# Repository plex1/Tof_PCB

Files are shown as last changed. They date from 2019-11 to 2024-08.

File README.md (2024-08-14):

# Time-of-Flight (ToF) PCB 

Contains optical transceiver for lidar or optical communication applications.

Laser diode options:
-  OPV310
-  SPL90 (not extensively tested)
   - Mods required: The A version of the NCP81074A of the MOSFET driver should be used. The supply voltage for the Mosfet driver should be increased from 5V to 12V. The peak power can be considerably increased with a higher voltage and lower shunt resistor value. In this case the duty cycle should be increased correspondingly for eye safety.

Photo diodes options:
- MTAPD-06-013
- SiPM MICRORB-10020-MLP-TR1

## Libraries

Uses the following libraries:
- KiCad Symbol Library: [ioda_symbols](https://github.com/plex1/ioda_symbols)
- KiCad Footprint Library: [ioda_footprints](https://github.com/plex1/ioda_footprints)

## Image
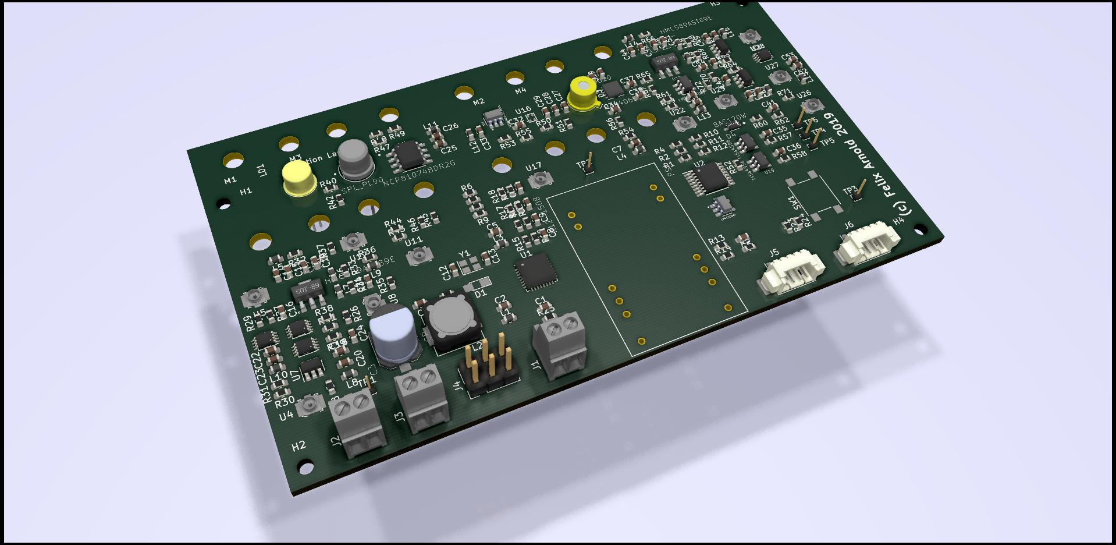
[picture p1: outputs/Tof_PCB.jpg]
Render


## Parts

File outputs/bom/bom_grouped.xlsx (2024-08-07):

Ref | Qnty | Value | Footprint | Digi-Key_PN | Part PCBWay will supply | Comment
C1, C2, C5, C6, C7, C15, C18, C19, C23, C26, C30, C40, C43, C45, C46, C47, C51, C53, C56, C58, C59, C60, C61, C62, C63, C64, C67, C69, C72, | 29 | 100nF | Capacitor_SMD:C_0603_1608Metric | 490-3285-1-ND | GRM188R72A104KA35D
C3, | 1 | 100uF | IODA_Lib:CAPAE660X800N | PCE5024CT-ND | EEE-FTH101XAP
C4, C8, C9, C10, C11, C14, C16, C17, C20, C21, C22, C25, C31, C32, C33, C34, C35, C36, C37, C38, C39, C41, C42, C44, C48, C49, C50, C52, C54, C55, C57, C65, C66, C68, C70, C71, C73, C74, C75, C76, C79, C80, C81, | 43 | 2.2uF | Capacitor_SMD:C_0603_1608Metric | 490-12740-1-ND | GRM188R61H225ME11D
C12, C13, | 2 | 16pF | Capacitor_SMD:C_0603_1608Metric | 399-7863-1-ND | C0603C160J5GACTU
C27, C28, C29, C78, | 4 | 10nF, 250V | Capacitor_SMD:C_0603_1608Metric | 732-12168-1-ND | 885342206006
D1, D6, | 2 | LED | LEDs:LED_0805 | 160-1423-1-ND | LTST-C171GKT
D4, | 1 | BAS170W | IODA_Lib:SOD2513X114N | BAS170WS-E3-08GICT-ND | BAS170WS-E3-08
D5, | 1 | SMBJ6.0A | OLIMEX_Diodes-FP:DO214AA_1(K)-2(A) | SMBJ6.0ABCT-ND | SMBJ6.0A
J1, J2, J3, J7, | 4 | Screw_Terminal_01x02 | IODA_Lib:ScrewTerminal_1x02_P2.54mm_Vertical | A98333-ND | 282834-2
J4, | 1 | Conn_02x03_Odd_Even | Connector_PinHeader_2.54mm:PinHeader_2x03_P2.54mm_Vertical | 609-3210-ND | 67996-206HLF | Part we will supply is substitute made in China.
J5, J6, | 2 | Conn_01x04 | Connector_Molex:Molex_PicoBlade_53261-0471_1x04-1MP_P1.25mm_Horizontal | WM7622CT-ND | 0532610471
L1, L3, L4, L5, L8, L10, L11, L12, L13, L14, L15, L16, L17, L20, L22, | 15 | bead | Inductor_SMD:L_0603_1608Metric | 490-5216-1-ND | BLM18HE152SN1D
L2, | 1 | 6.8uH | IODA_Lib:INDP7373X46N | 811-1180-1-ND | 46682C
L6, L7, L9, L18, L19, L21, | 6 | 10uH | Inductor_SMD:L_0603_1608Metric | 490-4025-1-ND | LQM18FN100M00D
R1, R6, R7, R8, R9, R23, R24, R27, R37, R39, | 10 | 0R | Resistor_SMD:R_0603_1608Metric | RMCF0603ZT0R00CT-ND | RMCF0603ZT0R00
R2, R3, R4, R13, R30, R31, R84, | 7 | 2.2k | Resistor_SMD:R_0603_1608Metric | RMCF0603FT2K20CT-ND | RMCF0603FT2K20
R5, R15, R18, R19, R20, R21, R22, R25, R33, R34, R54, R56, R57, R58, R60, R68, R69, R71, R80, R92, R93, | 21 | 10k | Resistor_SMD:R_0603_1608Metric | P10.0KHCT-ND | ERJ-3EKF1002V
R14, R29, R35, R42, R43, R55, R61, R72, R73, R78, R79, R86, | 12 | 200R | Resistor_SMD:R_0603_1608Metric | RHM200ADCT-ND | ESR03EZPF2000
R16, R40, R44, | 3 | 100R | Resistor_SMD:R_0603_1608Metric | RMCF0603FT100R | RMCF0603FT100R
R17, R51, R74, | 3 | 1M | Resistor_SMD:R_0603_1608Metric | 311-1.00MHRCT-ND | RC0603FR-071ML
R28, R45, R52, R53, R70, R85, | 6 | 50R | Resistor_SMD:R_0603_1608Metric | 541-56.0SCT-ND | CRCW060356R0FKEAHP
R32, R66, | 2 | 1.8R | Resistor_SMD:R_0603_1608Metric | 541-1.80CCCT-ND | CRCW08051R80FKEA
R47, | 1 | 4.7R | Resistor_SMD:R_0603_1608Metric | RNCP0603FTD4R70CT-ND | RNCP0603FTD4R70
R59, | 1 | 75R | Resistor_SMD:R_0603_1608Metric | RNCP0603FTD75R0CT-ND | RNCP0603FTD75R0
R62, R75, R76, R77, | 4 | 100k | Resistor_SMD:R_0603_1608Metric | RMCF0603FT110K | RMCF0603FT110K
R64, R89, R90, R91, | 4 | 22R | Resistor_SMD:R_0603_1608Metric | A129668CT-ND | CRGCQ0603F22R
TP1, TP2, TP3, TP4, TP5, TP6, TP7, TP8, TP9, TP10, | 10 | TestPoint | Connector_PinHeader_1.00mm:PinHeader_1x01_P1.00mm_Vertical | 732-5314-ND | 61300111121 | Part we will supply is substitute made in China.
U1, | 1 | ATmega328PB-MU | Package_DFN_QFN:QFN-32-1EP_5x5mm_P0.5mm_EP3.1x3.1mm | ATMEGA328PB-MURCT-ND | ATMEGA328PB-MUR
U4, U5, U8, U11, U12, U17, U22, U27, U28, U29, U32, U33, U35, | 13 | UMCC_50Ohm | IODA_Lib:Molex_734120114_UMC_RF_CONN_Vertical | A118077CT-ND | 1909763-1
U6, U25, | 2 | HMC589AST89E | IODA_Lib:SOT150P410X160-3N | 1127-3329-1-ND | HMC589AST89ETR
U7, U23, U24, | 3 | TLV3501 | IODA_Lib:SOT-23-6 | 296-43611-1-ND | TLV3501AIDR
U9, U10, U13, U26, U30, | 5 | NC7WZ00K8X | IODA_Lib:VSSOP-8_2.4x2.1mm_P0.5mm | NC7WZ00K8XCT-ND | NC7WZ00K8X
U14, | 1 | NCP81074BDR2G | IODA_Lib:SOIC-8-127P600X175-8N | NCP81074BDR2GOSCT-ND | NCP81074BDR2G
U15, | 1 | LMH6559MF | IODA_Lib:SOT95PX285X122-5N | 296-46123-1-ND | LMH6559MF
U18, U19, | 2 | ts5a4596 | IODA_Lib:SOT95PX285X122-5N | 296-17709-1-ND | TS5A4596DBVR
U20, | 1 | MAX40659 | IODA_Lib:SON65P300X300X80-9N | MAX40659ETA+TCT-ND | MAX40659ETA+T
U21, | 1 | LP5907MFX-3.3_NOPB | IODA_Lib:SOT95P280X145-5N | 296-38557-1-ND | LP5907MFX-3.3/NOPB
U31, | 1 | LM321 | Package_TO_SOT_SMD:SOT-23-5 | LM321MFX/NOPBCT-ND | LM321MFX/NOPB
U34, | 1 | NC7WZ16 | IODA_Lib:SOT65P210X110-6N | NC7WZ16P6XCT-ND | NC7WZ16P6X
Y1, | 1 | Crystal_GND24 | Crystal:Crystal_SMD_2520-4Pin_2.5x2.0mm | SER4068CT-ND | FA-20H 16.0000MF10Z-AJ0

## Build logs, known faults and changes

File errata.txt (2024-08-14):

M2.5 mounting holes too small
add 2 more mounting holes for a total of 6 for mechanical stability
add 2 more holes in front of base input for mounting of right angle for SiPM configuration
R26 and R27 should be 1.2k (490R) resistors instead of 0 Ohms
Put ferrite bead at 5V source of bias t for rf amplifiers
rename L to FB for ferrite beads
L2 6.8u to 6.8uH
100k uses digikey number for 110k resisotr
silksceen for screw terminals should be adopted
Test Point mounting holes are too small for pin header
TLV3501 digikey number was wrong
r38 should be soldered
r27/r28 -> 1.2k or maybe 470 ohms
amp directly at the photo diode / distance between nand driver and 220 ohm impence to rf amplifier can be longer,
with 50 impedance traces between
tapping with 200 ohms, the 200 ohm resistor should be close to the source, a 50 ohms track to the
can be longer
100 ohms resistor R43 too far from diode
MAX40659 more ground vias
Layout U6 is too close to the pulse generation circuit. It picks up some of the undesired negative clock edge.
Power Connector ground not always on the same side.
change R74 to 5/10M and R19 to 100k (and move to io with adc)
Remove R13, no attenuation required due to the common mode input range being lower than 5V, -> never goes above 4V
v_apd_r_sense PD0 not and analog input to the microcontroller, should have used PE2
holes of dcdc module bigger such that socekts can be inserted. (1mm holes)
APD, offset, Remove R56 and R54
optional 150pF at MAX4059
Buffer U34 seemed to emit noise into the Tx (TBD), remove or bypass?
dc/dc collides with optics base for the SiPM option
SiPM Vibas should be connected with 2x 50 Ohm resistors. See reference design, figure 8
SiPM fast output cannot drive 50 ohms, put a buffer in between or use slow output.
SiPM need negative voltage in current configuration.
make SiPM footprint pads slighty larger towards the top and bottpm
Add resistor to Rx of UART (and capacitor for filter), this solves to problem of the avr chip being powered by the ios
check tia ground pad, too big? make a little smaller,
tia should place vias, due to grounding and heat dissipation. more vias for sure, check footprint in general
tia is esd sensitive on input (not protected)
TIA alternative: MAX3658 (write in schematic, footprint compatible)
goold plating should be done on pcb
APD Biasing, use high resistor, then capacitor, then 50 ohm queching resistor, see datasheet LTC 6560 APD BIasing
place additional mounting holes for right angle mirror

Make a not that the apd pwm filter op amp output does not go over 5V-2V supply rail -> Common-mode voltage range
,(which is actually a good thing).
lockin_1 & lockin_2 rc filter should be added after the connector
comparator for lockin_1 and lockin_2 to receive signal lower than 5V
supply_lockin net is too long
LMH6559 needs a load of 100 Ohms, now it has 50 ohms, -> add 50 Ohms output resistance after the chip, including the 50 ohms source resistor that gives 100 ohms
The lockin output need to be amplified, currently the amplitudes are very small
the lockin ouptuts need to be filtered again just before the microcontroller. At the moment they are noisy. Can be solved by adding a sw filter.
add guard ring without solder mask around TIA
ground test point not large enough tou mount pin headers
place more ground test point with holes all over the board to place the ground pin of the probe into the hole, some can be mounted with pin headers to clip on ground banana plug
The 3.3V supply for the TIA has a long trace between regulator and TIA. It should be shortened or a ferrite bead should be placed close to the decoupling caps for filtering. Make sure that the regulator sees a sufficient capacity at its output by placing an additional capacitor.
The mosfet driver for the SPL90 diode needs 12 V supply. Works with 5V supply but at a lower current. 
5V should be regulated on the board when possible. For sure do not use a common cable for the motor and the TofPCB. I had this case and depending on the motor load the APD signal had a different amplitude due to the voltage drop on the cable.

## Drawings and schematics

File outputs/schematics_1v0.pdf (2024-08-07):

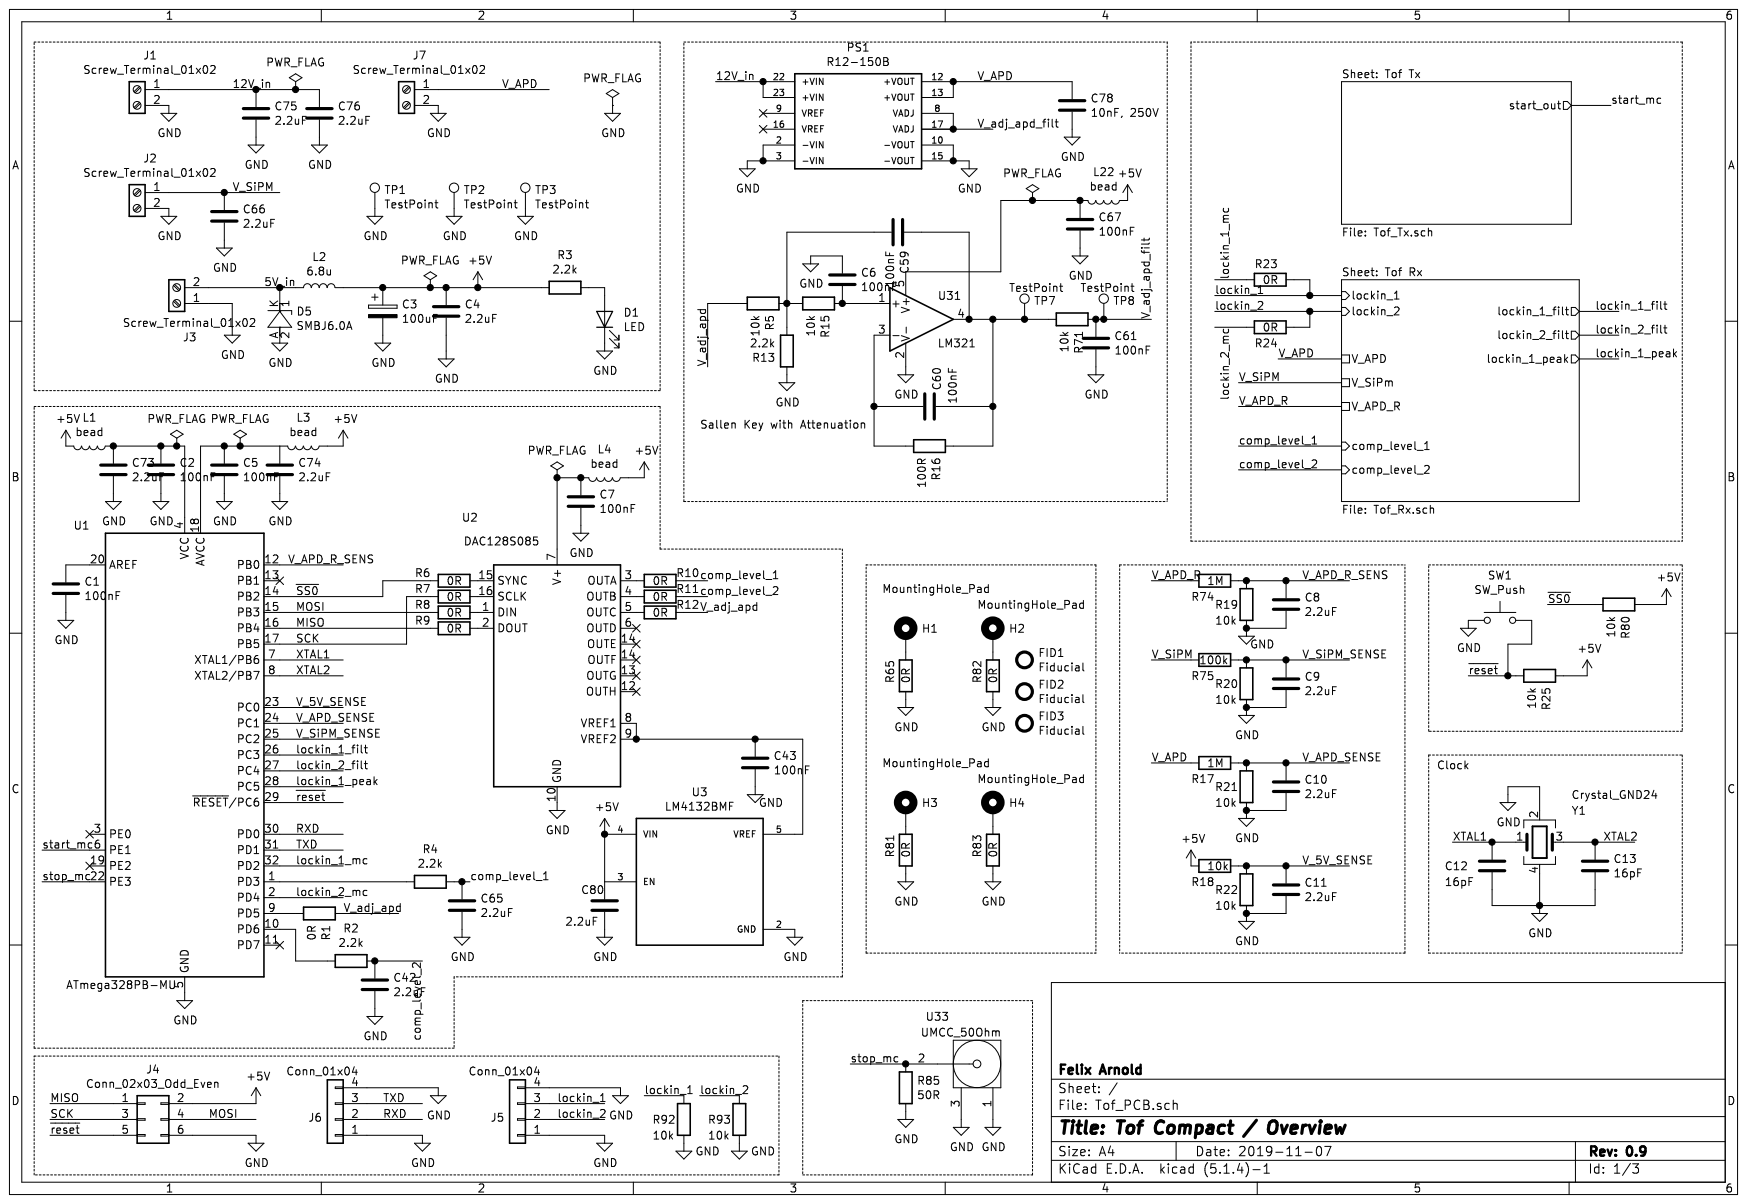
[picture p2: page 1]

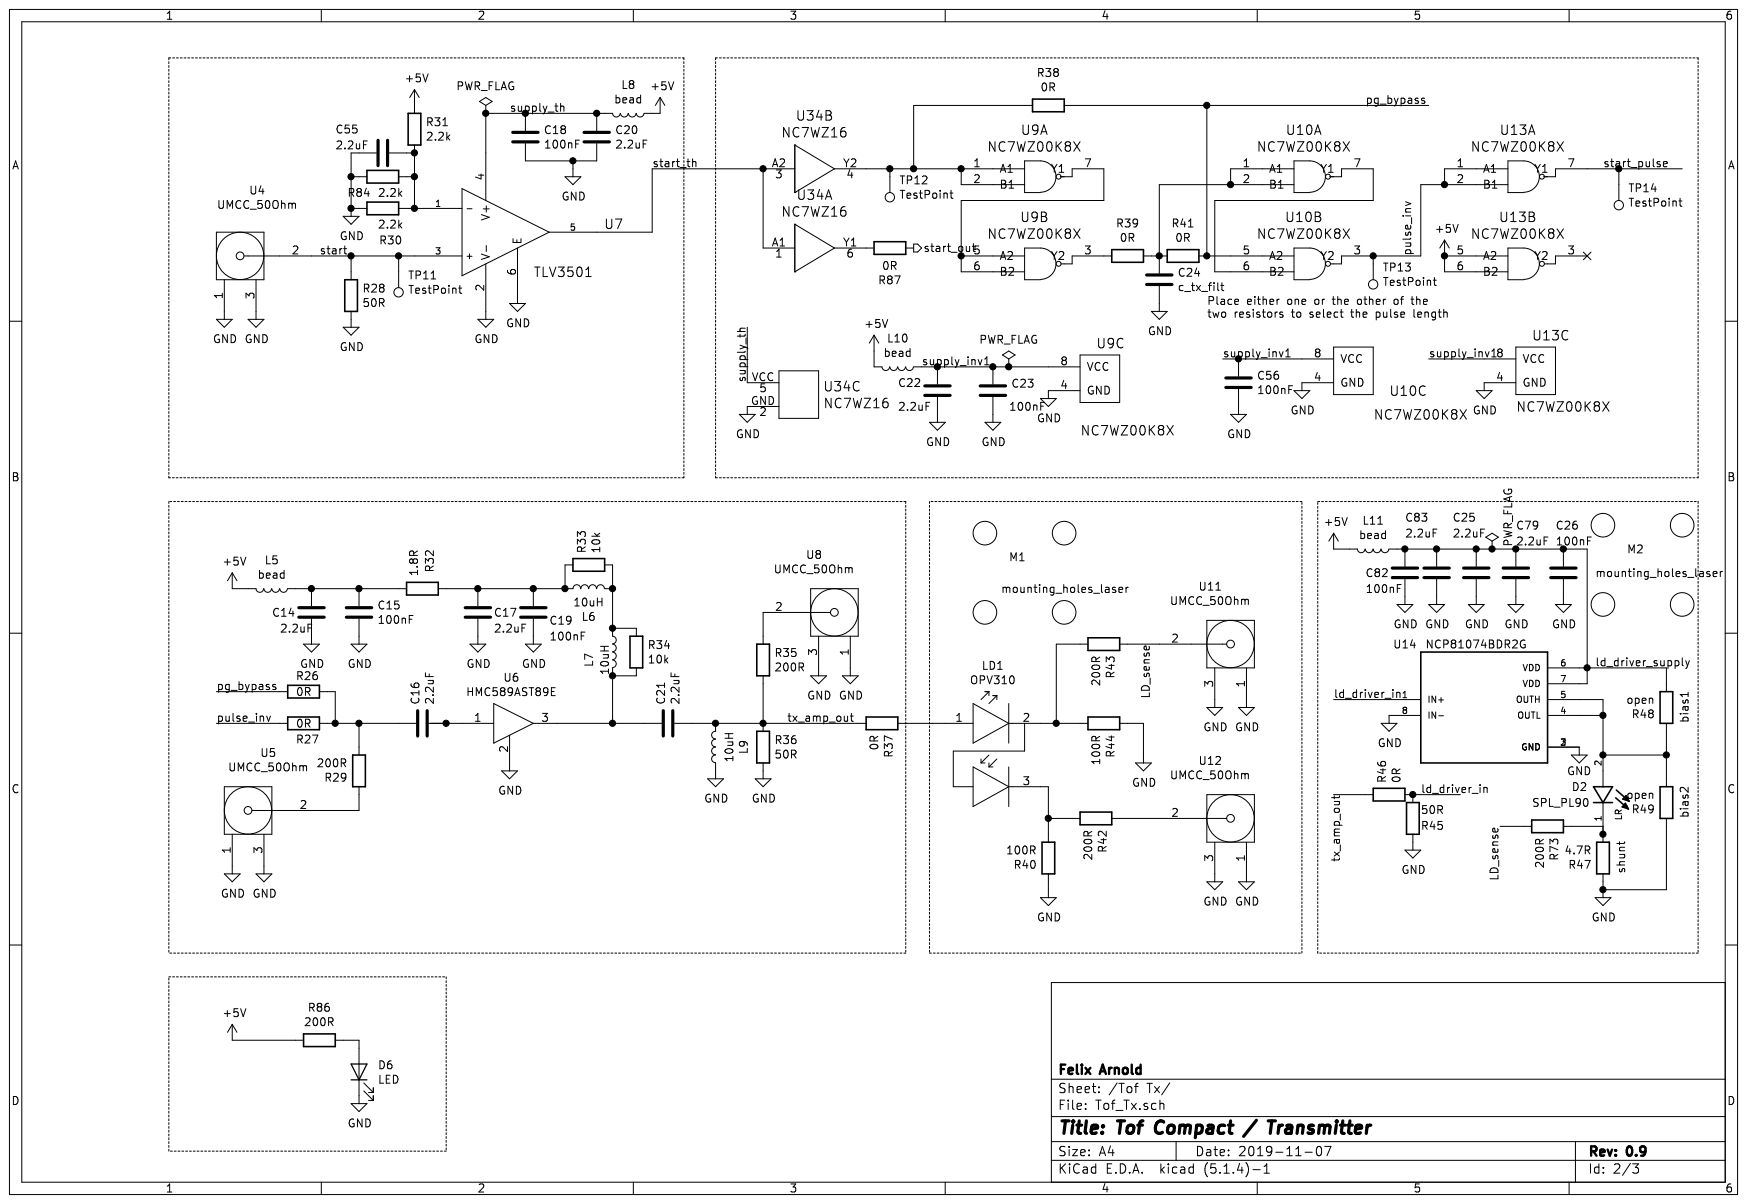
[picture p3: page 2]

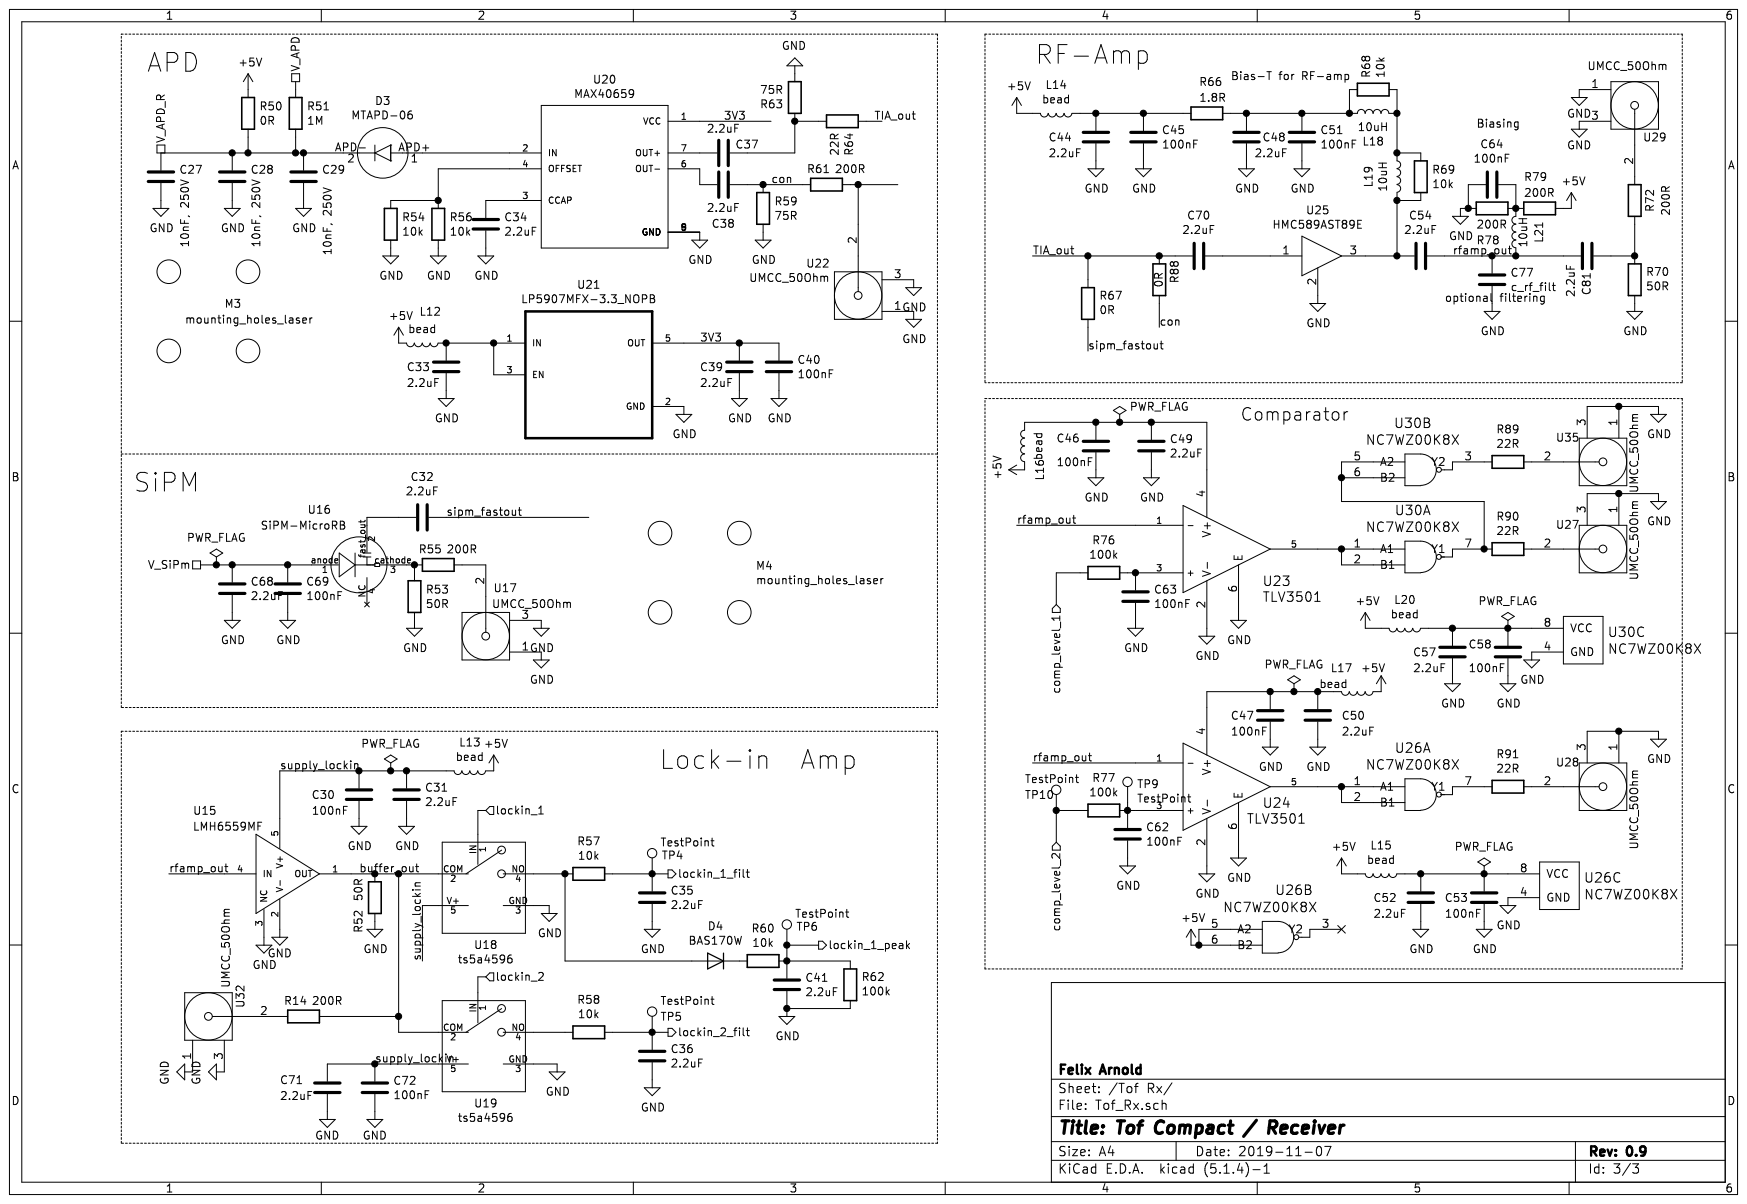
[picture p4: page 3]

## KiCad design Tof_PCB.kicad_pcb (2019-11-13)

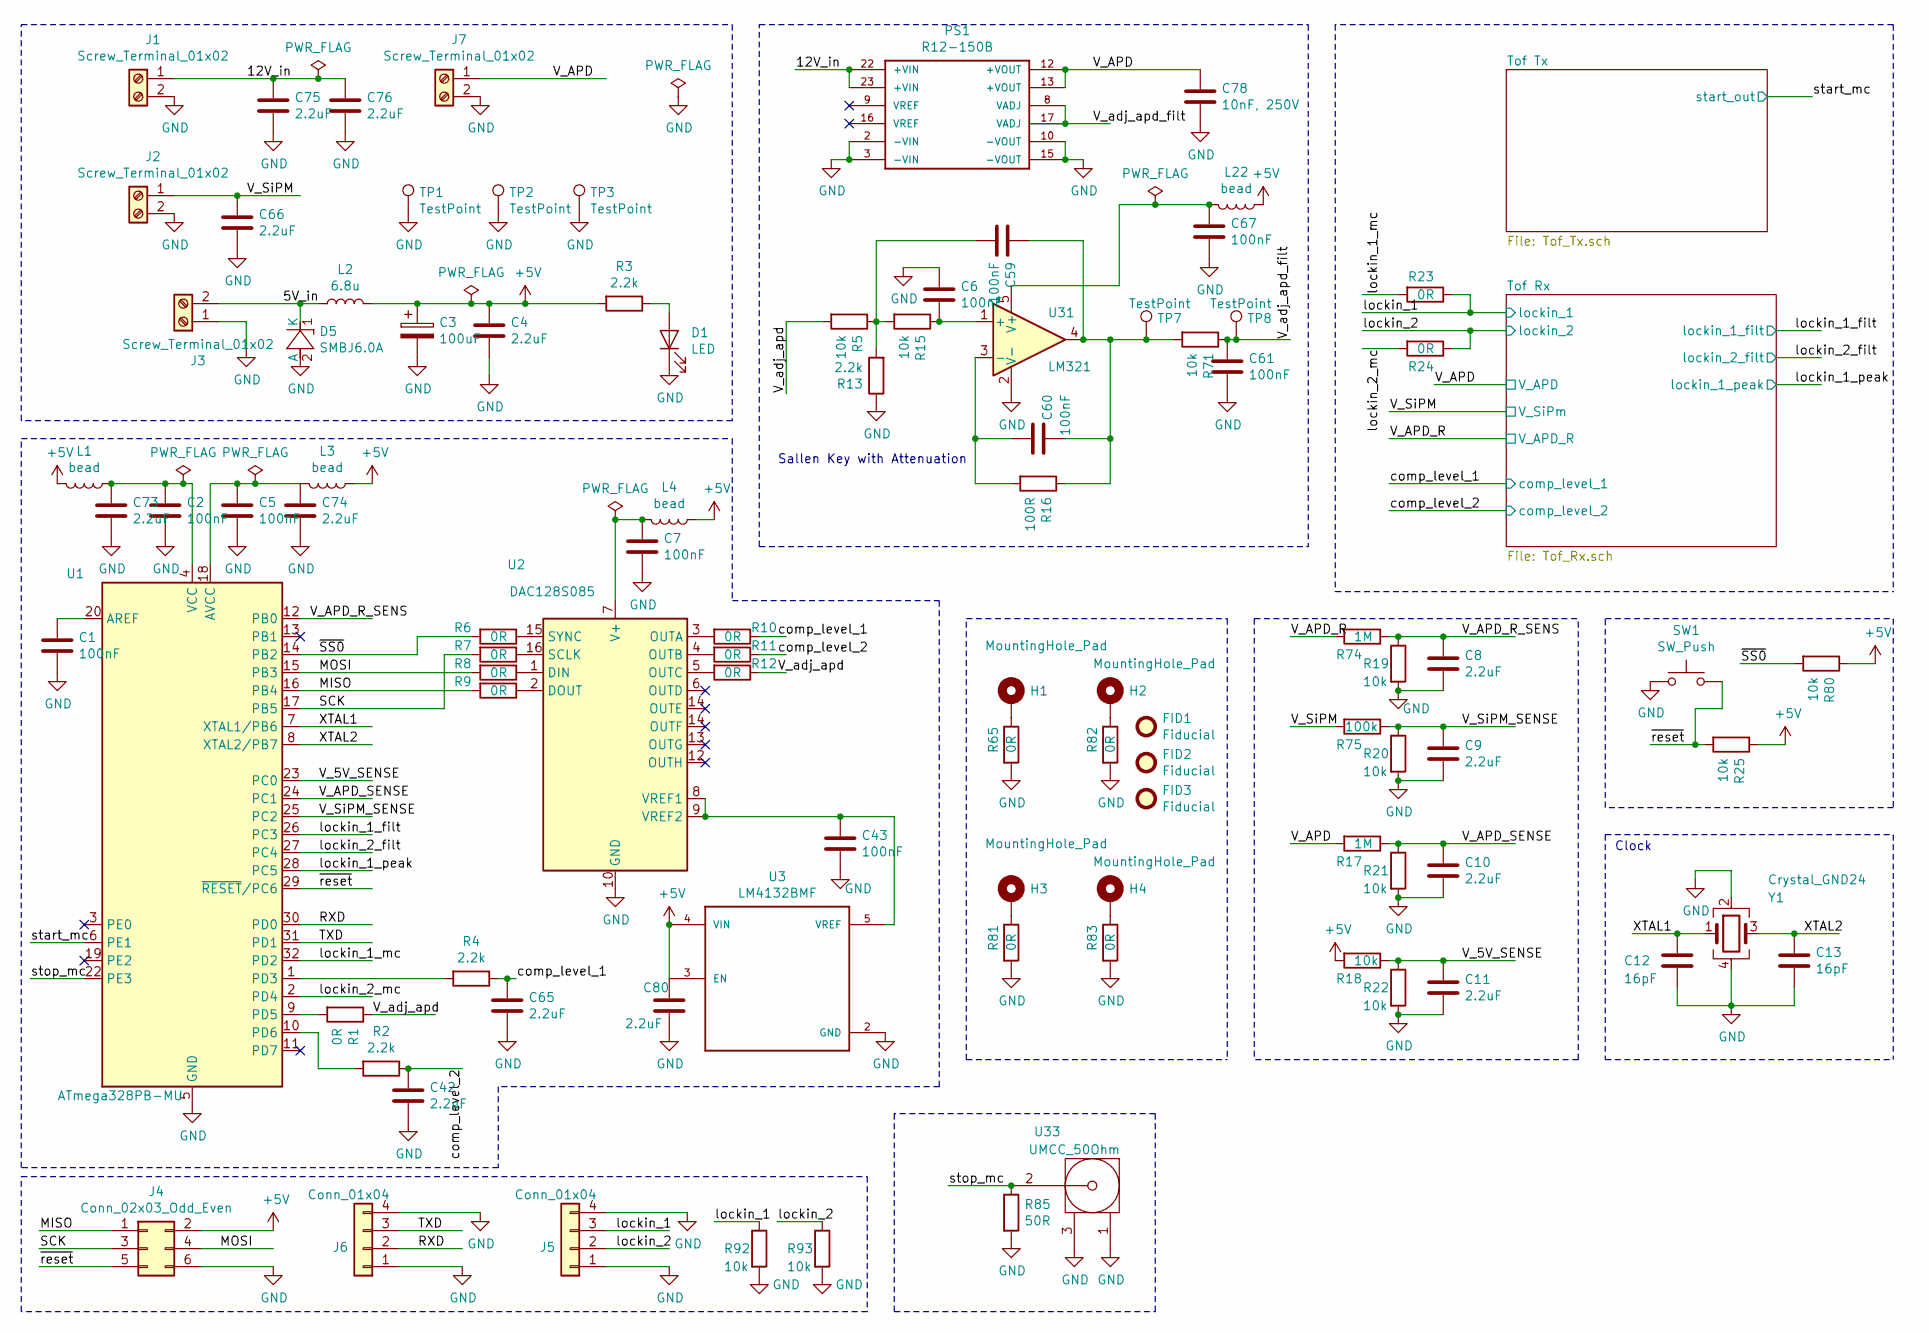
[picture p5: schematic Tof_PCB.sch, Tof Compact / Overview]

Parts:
C1, C2, C5, C6, C7, C43, C59, C60, C61, C67: 100nF; C_0603_1608Metric; Digi-Key_PN 490-3285-1-ND
C3: 100uF; CAPAE660X800N; Digi-Key_PN PCE5024CT-ND
C4, C8, C9, C10, C11, C42, C65, C66, C73, C74, C75, C76, C80: 2.2uF; C_0603_1608Metric; Digi-Key_PN 490-12740-1-ND
C12, C13: 16pF; C_0603_1608Metric; Digi-Key_PN 399-7863-1-ND
C78: 10nF, 250V; C_0603_1608Metric; Digi-Key_PN 732-12168-1-ND
D1: LED; LED_0805; Digi-Key_PN 160-1423-1-ND
D5: SMBJ6.0A; DO214AA_1(K)-2(A); Digi-Key_PN SMBJ6.0ABCT-ND
FID1, FID2, FID3: Fiducial; MF_Aesthetics-FIDUCIAL_100MIL
H1, H2, H3, H4: MountingHole_Pad; MountingHole_2.2mm_M2
J1, J2, J3, J7: Screw_Terminal_01x02; ScrewTerminal_1x02_P2.54mm_Vertical; Digi-Key_PN A98333-ND
J4: Conn_02x03_Odd_Even; PinHeader_2x03_P2.54mm_Vertical; Digi-Key_PN 609-3210-ND
J5, J6: Conn_01x04; Molex_PicoBlade_53261-0471_1x04-1MP_P1.25mm_Horizontal; Digi-Key_PN WM7622CT-ND
L1, L3, L4, L22: bead; L_0603_1608Metric; Digi-Key_PN 490-5216-1-ND
L2: 6.8u; INDP7373X46N; Digi-Key_PN 811-1180-1-ND
PS1: R12-150B; RECOM_CONV_R12-150B; Digi-Key_PN 945-2053-5-ND
R1, R6, R7, R8, R9, R10, R11, R12, R23, R24, R65, R81, R82, R83: 0R; R_0603_1608Metric; Digi-Key_PN RMCF0603ZT0R00CT-ND
R2, R3, R4, R13: 2.2k; R_0603_1608Metric; Digi-Key_PN RMCF0603FT2K20CT-ND
R5, R15, R18, R19, R20, R21, R22, R25, R71, R80, R92, R93: 10k; R_0603_1608Metric; Digi-Key_PN P10.0KHCT-ND
R16: 100R; R_0603_1608Metric; Digi-Key_PN RMCF0603FT100R
R17, R74: 1M; R_0603_1608Metric; Digi-Key_PN 311-1.00MHRCT-ND
R75: 100k; R_0603_1608Metric; Digi-Key_PN RMCF0603FT110K
R85: 50R; R_0603_1608Metric; Digi-Key_PN 541-56.0SCT-ND
SW1: SW_Push; SW_Push_1P1T_NO_6x6mm_H9.5mm; Digi-Key_PN CKN9112TR-ND
TP1, TP2, TP3, TP7, TP8: TestPoint; PinHeader_1x01_P1.00mm_Vertical; Digi-Key_PN 732-5314-ND
U1: ATmega328PB-MU; QFN-32-1EP_5x5mm_P0.5mm_EP3.1x3.1mm; Digi-Key_PN ATMEGA328PB-MURCT-ND
U2: DAC128S085; TSSOP-16_4.4x5mm_P0.65mm; Digi-Key_PN DAC128S085CIMT/NOPB
U3: LM4132BMF; SOT95P280X145-5N; Digi-Key_PN LM4132BMF-4.1/NOPBCT-ND
U31: LM321; SOT-23-5; Digi-Key_PN LM321MFX/NOPBCT-ND
U33: UMCC_50Ohm; Molex_734120114_UMC_RF_CONN_Vertical; Digi-Key_PN A118077CT-ND
Y1: Crystal_GND24; Crystal_SMD_2520-4Pin_2.5x2.0mm; Digi-Key_PN SER4068CT-ND

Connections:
+5V: C3.1, C4.1, C80.1, J4.2, L1.2, L2.2, L3.1, L4.1, L22.1, R3.2, R18.2, R25.1, R80.1, U3.3 (EN), U3.4 (VIN); also elsewhere on the board
/5V_in: D5.1 (K), J3.2, L2.1
/12V_in: C75.1, C76.1, J1.1, PS1.22 (+VIN), PS1.23 (+VIN)
/MISO: J4.1, R9.2, U1.16 (PB4)
/MOSI: J4.4, R8.2, U1.15 (PB3)
/RXD: J6.2, U1.30 (PD0)
/SCK: J4.3, R7.2, U1.17 (PB5)
/TXD: J6.3, U1.31 (PD1)
/V_5V_SENSE: C11.1, R18.1, R22.1, U1.23 (PC0)
/V_APD: C78.1, J7.1, PS1.12 (+VOUT), PS1.13 (+VOUT), R17.2; also elsewhere on the board
/V_APD_R: R74.2; also elsewhere on the board
/V_APD_R_SENS: C8.1, R19.1, R74.1, U1.12 (PB0)
/V_APD_SENSE: C10.1, R17.1, R21.1, U1.24 (PC1)
/V_SiPM: C66.1, J2.1, R75.2; also elsewhere on the board
/V_SiPM_SENSE: C9.1, R20.1, R75.1, U1.25 (PC2)
/V_adj_apd: R1.1, R5.2, R12.1
/V_adj_apd_filt: C61.1, PS1.8 (VADJ), PS1.17 (VADJ), R71.1, TP8.1
/XTAL1: C12.1, U1.7 (XTAL1/PB6), Y1.1
/XTAL2: C13.1, U1.8 (XTAL2/PB7), Y1.3
/comp_level_1: C65.1, R4.1, R10.1; also elsewhere on the board
/comp_level_2: C42.1, R2.1, R11.1; also elsewhere on the board
/lockin_1: J5.3, R23.1, R92.1; also elsewhere on the board
/lockin_1_filt: U1.26 (PC3); also elsewhere on the board
/lockin_1_mc: R23.2, U1.32 (PD2)
/lockin_1_peak: U1.28 (PC5); also elsewhere on the board
/lockin_2: J5.2, R24.1, R93.1; also elsewhere on the board
/lockin_2_filt: U1.27 (PC4); also elsewhere on the board
/lockin_2_mc: R24.2, U1.2 (PD4)
/start_mc: U1.6 (PE1); also elsewhere on the board
/stop_mc: R85.1, U1.22 (PE3), U33.2
/~SS0: R6.2, R80.2, U1.14 (PB2)
/~reset: J4.5, R25.2, SW1.2, U1.29 (~RESET~/PC6)
GND: C1.2, C2.2, C3.2, C4.2, C5.2, C6.1, C7.2, C8.2, C9.2, C10.2, C11.2, C12.2, C13.2, C42.2, C43.2, C61.2, C65.2, C66.2, C67.2, C73.2, C74.2, C75.2, C76.2, C78.2, C80.2, D1.1 (K), D5.2 (A), J1.2, J2.2, J3.1, J4.6, J5.1, J5.4, J6.1, J6.4, J7.2, PS1.2 (-VIN), PS1.3 (-VIN), PS1.10 (-VOUT), PS1.15 (-VOUT), R13.1, R19.2, R20.2, R21.2, R22.2, R65.2, R81.2, R82.2, R83.2, R85.2, R92.2, R93.2, SW1.1, TP1.1, TP2.1, TP3.1, U1.5 (GND), U1.21 (GND), U1.33 (GND), U2.10 (GND), U3.2 (GND), U31.2 (V-), U33.1, U33.3, Y1.2, Y1.4; also elsewhere on the board
unnamed: C1.1, U1.20 (AREF)
unnamed: C2.1, C73.1, L1.1, U1.4 (VCC)
unnamed: C5.1, C74.1, L3.2, U1.18 (AVCC)
unnamed: C6.2, R15.1, U31.1 (+)
unnamed: C7.1, L4.2, U2.7 (V+)
unnamed: C43.1, U2.8 (VREF1), U2.9 (VREF2), U3.5 (VREF)
unnamed: C59.1, C60.1, R16.1, R71.2, TP7.1, U31.4
unnamed: C59.2, R5.1, R13.2, R15.2
unnamed: C60.2, R16.2, U31.3 (-)
unnamed: C67.1, L22.2, U31.5 (V+)
unnamed: D1.2 (A), R3.1
unnamed: H1.1, R65.1
unnamed: H2.1, R82.1
unnamed: H3.1, R81.1
unnamed: H4.1, R83.1
unnamed: R1.2, U1.9 (PD5)
unnamed: R2.2, U1.10 (PD6)
unnamed: R4.2, U1.1 (PD3)
unnamed: R6.1, U2.15 (SYNC)
unnamed: R7.1, U2.16 (SCLK)
unnamed: R8.1, U2.1 (DIN)
unnamed: R9.1, U2.2 (DOUT)
unnamed: R10.2, U2.3 (OUTA)
unnamed: R11.2, U2.4 (OUTB)
unnamed: R12.2, U2.5 (OUTC)

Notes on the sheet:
Clock
Sallen Key with Attenuation

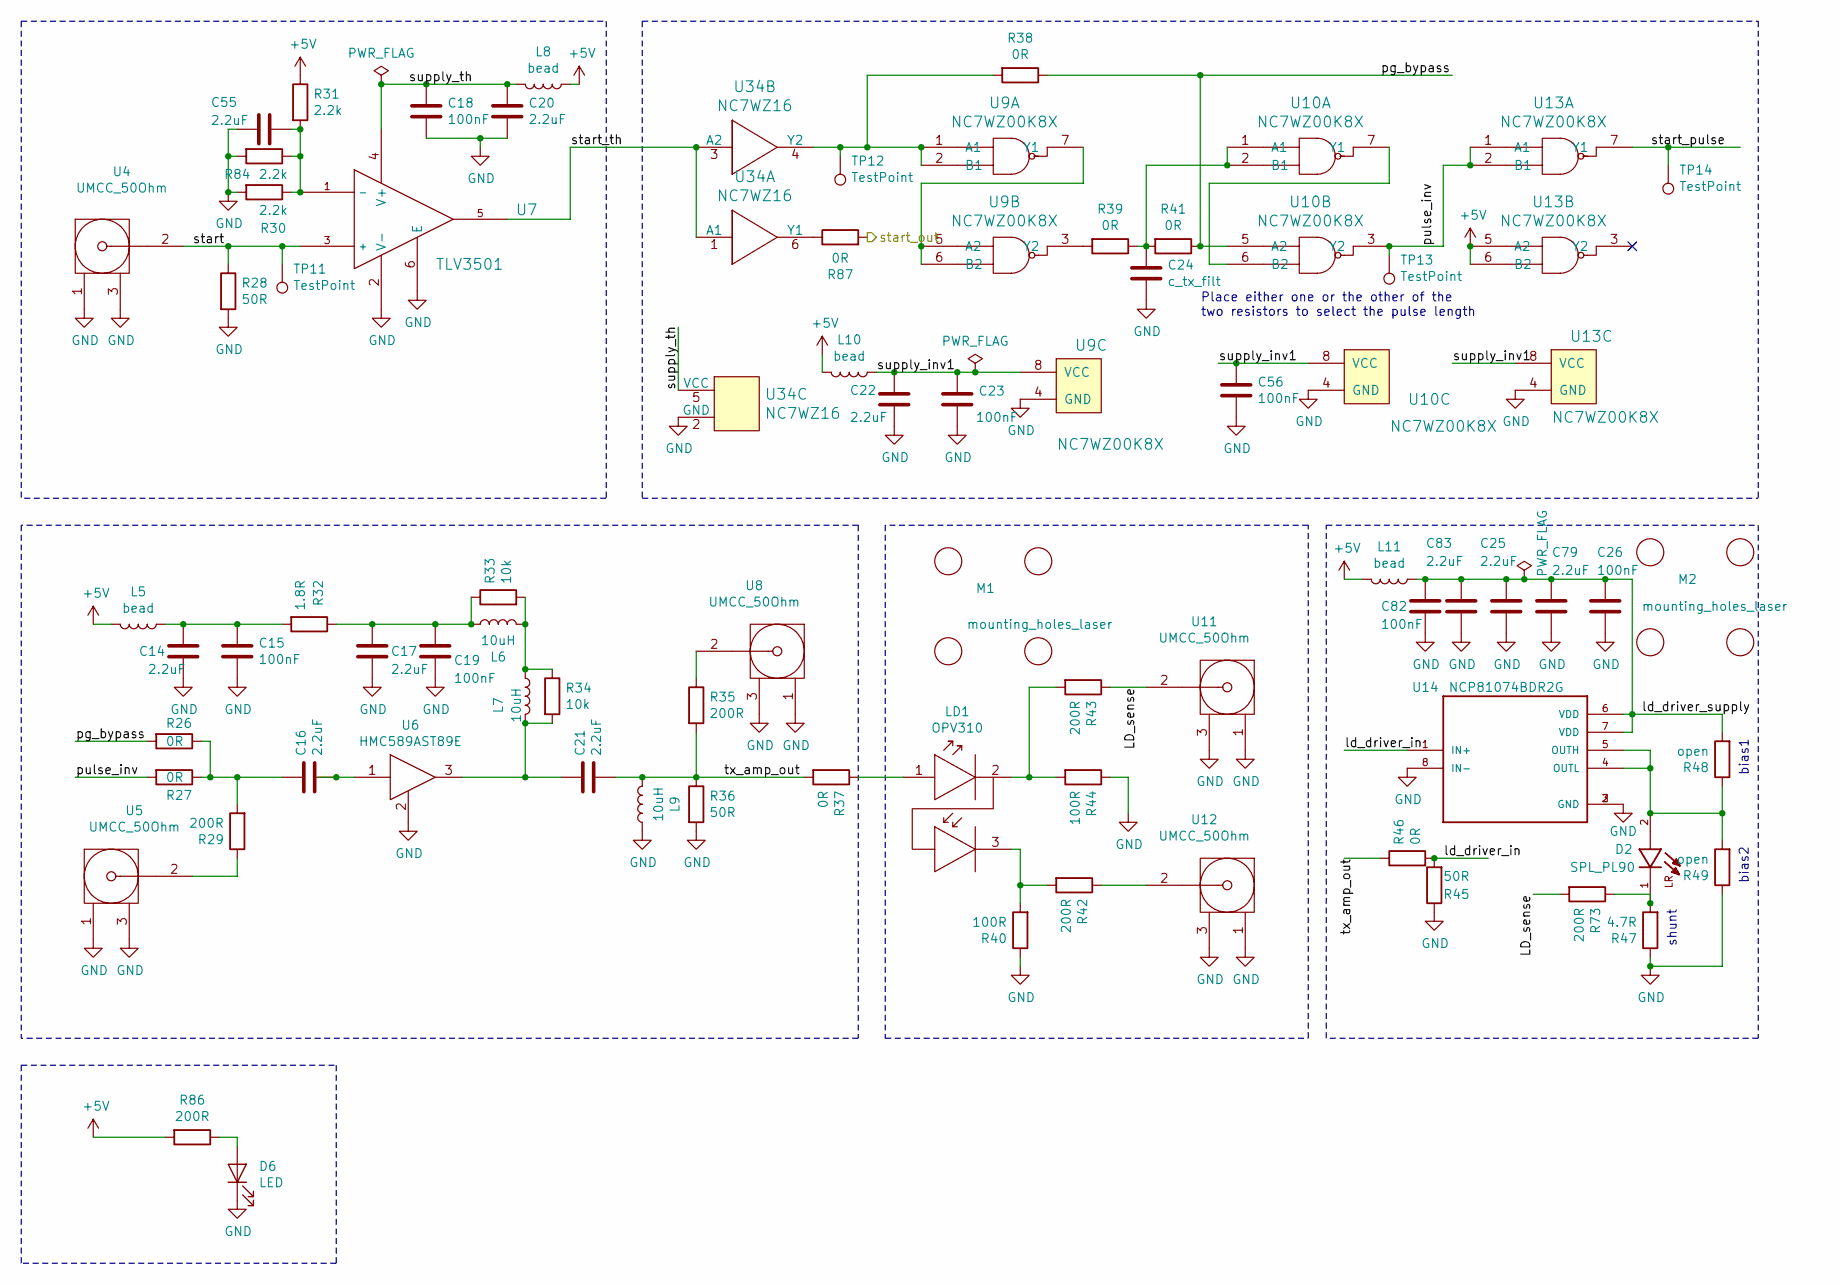
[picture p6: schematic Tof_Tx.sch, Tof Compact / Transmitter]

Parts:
C14, C16, C17, C20, C21, C22, C25, C55, C79, C83: 2.2uF; C_0603_1608Metric; Digi-Key_PN 490-12740-1-ND
C15, C18, C19, C23, C26, C56, C82: 100nF; C_0603_1608Metric; Digi-Key_PN 490-3285-1-ND
C24: c_tx_filt; C_0603_1608Metric
D2: SPL_PL90; LEDRD254W40D590H700; Digi-Key_PN 475-3533-ND
D6: LED; LED_0805; Digi-Key_PN 160-1423-1-ND
L5, L8, L10, L11: bead; L_0603_1608Metric; Digi-Key_PN 490-5216-1-ND
L6, L7, L9: 10uH; L_0603_1608Metric; Digi-Key_PN 490-4025-1-ND
LD1: OPV310; opv310; Digi-Key_PN 365-1879-ND
M1, M2: mounting_holes_laser; mounting_holes_17.8mm
R26, R27, R37, R38, R39, R41, R46, R87: 0R; R_0603_1608Metric; Digi-Key_PN RMCF0603ZT0R00CT-ND
R28, R36, R45: 50R; R_0603_1608Metric; Digi-Key_PN 541-56.0SCT-ND
R29, R35, R42, R43, R73, R86: 200R; R_0603_1608Metric; Digi-Key_PN RHM200ADCT-ND
R30, R31, R84: 2.2k; R_0603_1608Metric; Digi-Key_PN RMCF0603FT2K20CT-ND
R32: 1.8R; R_0603_1608Metric; Digi-Key_PN 541-1.80CCCT-ND
R33, R34: 10k; R_0603_1608Metric; Digi-Key_PN P10.0KHCT-ND
R40, R44: 100R; R_0603_1608Metric; Digi-Key_PN RMCF0603FT100R
R47: 4.7R; R_0603_1608Metric; Digi-Key_PN RNCP0603FTD4R70CT-ND
R48, R49: open; R_0603_1608Metric
TP11, TP12, TP13, TP14: TestPoint; TestPoint_Pad_1.0x1.0mm
U4, U5, U8, U11, U12: UMCC_50Ohm; Molex_734120114_UMC_RF_CONN_Vertical; Digi-Key_PN A118077CT-ND
U6: HMC589AST89E; SOT150P410X160-3N; Digi-Key_PN 1127-3329-1-ND
U7: TLV3501; SOT-23-6; Digi-Key_PN 296-43611-1-ND
U9, U10, U13: NC7WZ00K8X; VSSOP-8_2.4x2.1mm_P0.5mm; Digi-Key_PN NC7WZ00K8XCT-ND
U14: NCP81074BDR2G; SOIC-8-127P600X175-8N; Digi-Key_PN NCP81074BDR2GOSCT-ND
U34: NC7WZ16; SOT65P210X110-6N; Digi-Key_PN NC7WZ16P6XCT-ND

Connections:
+5V: L5.2, L8.1, L10.2, L11.2, R31.1, R86.2, U13.5 (A2), U13.6 (B2); also elsewhere on the board
/Tof Tx/LD_sense: R43.1, R73.2, U11.2
/Tof Tx/ld_driver_in: R45.2, R46.2, U14.1 (IN+)
/Tof Tx/ld_driver_supply: C25.1, C26.1, C79.1, C82.1, C83.1, L11.1, R48.2, U14.6 (VDD), U14.7 (VDD)
/Tof Tx/pg_bypass: R26.2, R38.1, R41.1, U10.5 (A2)
/Tof Tx/pulse_inv: R27.2, TP13.1, U10.3 (Y2), U13.1 (A1), U13.2 (B1)
/Tof Tx/start: R28.1, TP11.1, U4.2, U7.3 (+)
/Tof Tx/start_pulse: TP14.1, U13.7 (Y1)
/Tof Tx/start_th: U7.5, U34.1 (A1), U34.3 (A2)
/Tof Tx/supply_inv1: C22.1, C23.1, C56.1, L10.1, U9.8 (VCC), U10.8 (VCC), U13.8 (VCC)
/Tof Tx/supply_th: C18.1, C20.1, L8.2, U7.4 (V+), U34.5 (VCC)
/Tof Tx/tx_amp_out: C21.2, L9.2, R35.2, R36.1, R37.2, R46.1
/start_mc: R87.2; also elsewhere on the board
GND: C14.2, C15.2, C17.2, C18.2, C19.2, C20.2, C22.2, C23.2, C24.2, C25.2, C26.2, C55.2, C56.2, C79.2, C82.2, C83.2, D6.1 (K), L9.1, R28.2, R30.2, R36.2, R40.1, R44.1, R45.1, R47.1, R49.1, R84.2, U4.1, U4.3, U5.1, U5.3, U6.2, U7.2 (V-), U7.6 (E), U8.1, U8.3, U9.4 (GND), U10.4 (GND), U11.1, U11.3, U12.1, U12.3, U13.4 (GND), U14.2 (GND), U14.3 (GND), U14.8 (IN-), U34.2 (GND); also elsewhere on the board
unnamed: C14.1, C15.1, L5.1, R32.2
unnamed: C16.1, R26.1, R27.1, R29.2
unnamed: C16.2, U6.1
unnamed: C17.1, C19.1, L6.1, R32.1, R33.1
unnamed: C21.1, L7.2, R34.2, U6.3
unnamed: C24.1, R39.1, R41.2, U10.1 (A1), U10.2 (B1)
unnamed: C55.1, R30.1, R31.2, R84.1, U7.1 (-)
unnamed: D2.1, R47.2, R73.1
unnamed: D2.2, R48.1, R49.2, U14.4 (OUTL), U14.5 (OUTH)
unnamed: D6.2 (A), R86.1
unnamed: L6.2, L7.1, R33.2, R34.1
unnamed: LD1.1, R37.1
unnamed: LD1.2, R43.2, R44.2
unnamed: LD1.3, R40.2, R42.2
unnamed: R29.1, U5.2
unnamed: R35.1, U8.2
unnamed: R38.2, TP12.1, U9.1 (A1), U9.2 (B1), U34.4 (Y2)
unnamed: R39.2, U9.3 (Y2)
unnamed: R42.1, U12.2
unnamed: R87.1, U34.6 (Y1)
unnamed: U9.5 (A2), U9.6 (B2), U9.7 (Y1)
unnamed: U10.6 (B2), U10.7 (Y1)

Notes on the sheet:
Place either one or the other of the two resistors to select the pulse length
bias1
bias2
shunt

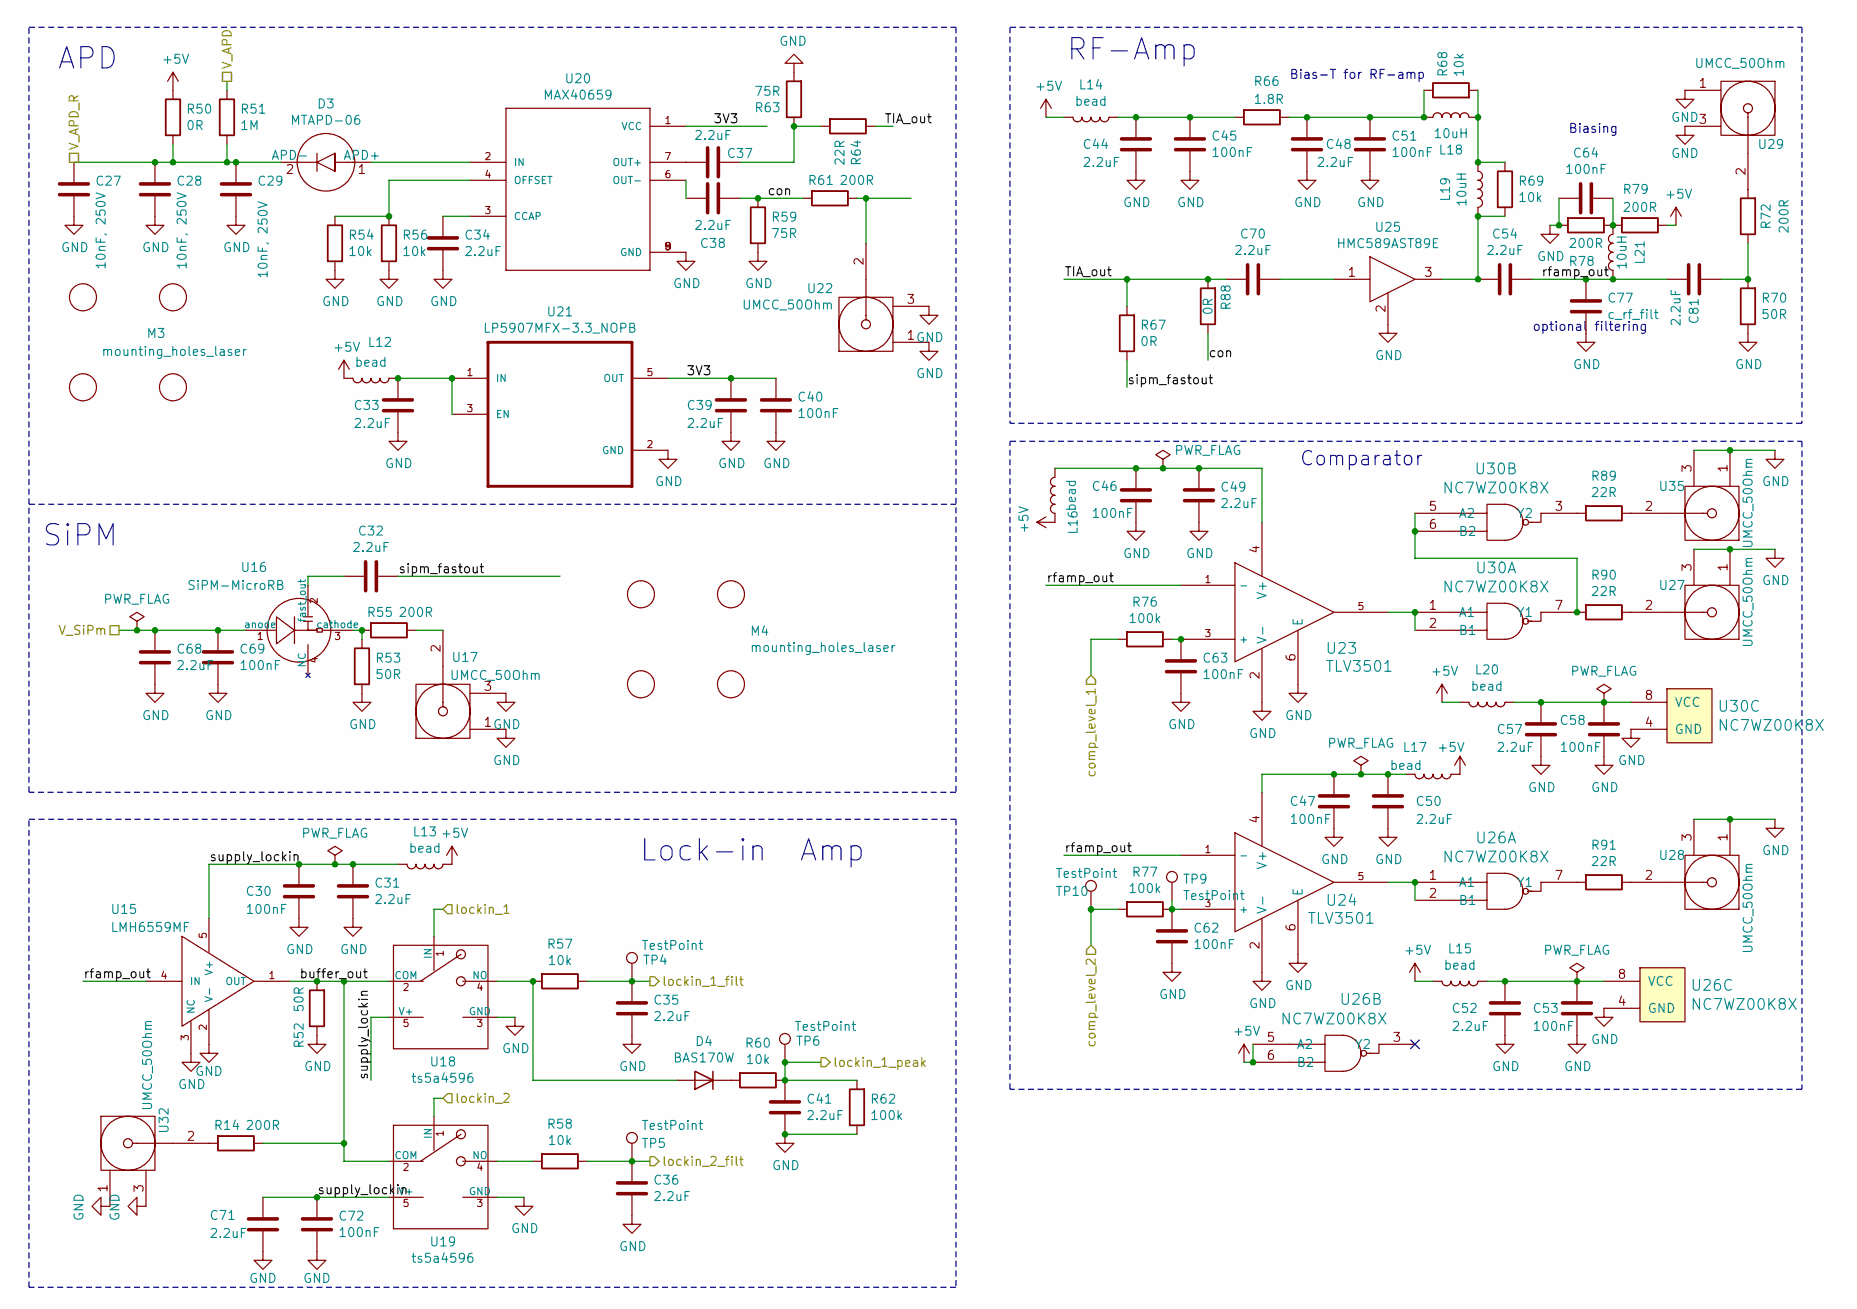
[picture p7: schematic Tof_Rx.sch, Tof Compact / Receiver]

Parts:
C27, C28, C29: 10nF, 250V; C_0603_1608Metric; Digi-Key_PN 732-12168-1-ND
C30, C40, C45, C46, C47, C51, C53, C58, C62, C63, C64, C69, C72: 100nF; C_0603_1608Metric; Digi-Key_PN 490-3285-1-ND
C31, C32, C33, C34, C35, C36, C37, C38, C39, C41, C44, C48, C49, C50, C52, C54, C57, C68, C70, C71, C81: 2.2uF; C_0603_1608Metric; Digi-Key_PN 490-12740-1-ND
C77: c_rf_filt; C_0603_1608Metric
D3: MTAPD-06; Digi-Key_PN 1125-1298-ND
D4: BAS170W; SOD2513X114N; Digi-Key_PN BAS170WS-E3-08GICT-ND
L12, L13, L14, L15, L16, L17, L20: bead; L_0603_1608Metric; Digi-Key_PN 490-5216-1-ND
L18, L19, L21: 10uH; L_0603_1608Metric; Digi-Key_PN 490-4025-1-ND
M3, M4: mounting_holes_laser; mounting_holes_17.8mm
R14, R55, R61, R72, R78, R79: 200R; R_0603_1608Metric; Digi-Key_PN RHM200ADCT-ND
R50, R67, R88: 0R; R_0603_1608Metric; Digi-Key_PN RMCF0603ZT0R00CT-ND
R51: 1M; R_0603_1608Metric; Digi-Key_PN 311-1.00MHRCT-ND
R52, R53, R70: 50R; R_0603_1608Metric; Digi-Key_PN 541-56.0SCT-ND
R54, R56, R57, R58, R60, R68, R69: 10k; R_0603_1608Metric; Digi-Key_PN P10.0KHCT-ND
R59, R63: 75R; R_0603_1608Metric; Digi-Key_PN RNCP0603FTD75R0CT-ND
R62, R76, R77: 100k; R_0603_1608Metric; Digi-Key_PN RMCF0603FT110K
R64, R89, R90, R91: 22R; R_0603_1608Metric; Digi-Key_PN A129668CT-ND
R66: 1.8R; R_0603_1608Metric; Digi-Key_PN 541-1.80CCCT-ND
TP4, TP5, TP6, TP9, TP10: TestPoint; PinHeader_1x01_P1.00mm_Vertical; Digi-Key_PN 732-5314-ND
U15: LMH6559MF; SOT95PX285X122-5N; Digi-Key_PN 296-46123-1-ND
U16: SiPM-MicroRB; CWDFN4_1.5x1.8_0.8P; Digi-Key_PN MICRORB-10020-MLP-TR1OS-ND
U17, U22, U27, U28, U29, U32, U35: UMCC_50Ohm; Molex_734120114_UMC_RF_CONN_Vertical; Digi-Key_PN A118077CT-ND
U18, U19: ts5a4596; SOT95PX285X122-5N; Digi-Key_PN 296-17709-1-ND
U20: MAX40659; SON65P300X300X80-9N; Digi-Key_PN MAX40659ETA+TCT-ND
U21: LP5907MFX-3.3_NOPB; SOT95P280X145-5N; Digi-Key_PN 296-38557-1-ND
U23, U24: TLV3501; SOT-23-6; Digi-Key_PN 296-43611-1-ND
U25: HMC589AST89E; SOT150P410X160-3N; Digi-Key_PN 1127-3329-1-ND
U26, U30: NC7WZ00K8X; VSSOP-8_2.4x2.1mm_P0.5mm; Digi-Key_PN NC7WZ00K8XCT-ND

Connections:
+5V: L12.2, L13.1, L14.2, L15.2, L16.1, L17.1, L20.2, R50.1, R79.1, U26.5 (A2), U26.6 (B2); also elsewhere on the board
/Tof Rx/3V3: C39.1, C40.1, U20.1 (VCC), U21.5 (OUT)
/Tof Rx/TIA_out: C70.1, R64.1, R67.2, R88.2
/Tof Rx/buffer_out: R14.1, R52.2, U15.1 (OUT), U18.2 (COM), U19.2 (COM)
/Tof Rx/con: C38.2, R59.1, R61.2, R88.1
/Tof Rx/rfamp_out: C54.2, C77.1, C81.2, L21.1, U15.4 (IN), U23.1 (-), U24.1 (-)
/Tof Rx/sipm_fastout: C32.2, R67.1
/Tof Rx/supply_lockin: C30.1, C31.1, C71.1, C72.1, L13.2, U15.5 (V+), U18.5 (V+), U19.5 (V+)
/V_APD: R51.1; also elsewhere on the board
/V_APD_R: C27.1, C28.1, C29.1, D3.2 (APD-), R50.2, R51.2; also elsewhere on the board
/V_SiPM: C68.1, C69.1, U16.1 (anode); also elsewhere on the board
/comp_level_1: R76.2; also elsewhere on the board
/comp_level_2: R77.2, TP10.1; also elsewhere on the board
/lockin_1: U18.1 (IN); also elsewhere on the board
/lockin_1_filt: C35.1, R57.1, TP4.1; also elsewhere on the board
/lockin_1_peak: C41.1, R60.1, R62.2, TP6.1; also elsewhere on the board
/lockin_2: U19.1 (IN); also elsewhere on the board
/lockin_2_filt: C36.1, R58.1, TP5.1; also elsewhere on the board
GND: C27.2, C28.2, C29.2, C30.2, C31.2, C33.2, C34.2, C35.2, C36.2, C39.2, C40.2, C41.2, C44.2, C45.2, C46.2, C47.2, C48.2, C49.2, C50.2, C51.2, C52.2, C53.2, C57.2, C58.2, C62.2, C63.2, C64.1, C68.2, C69.2, C71.2, C72.2, C77.2, R52.1, R53.2, R54.2, R56.2, R59.2, R62.1, R63.2, R70.1, R78.2, U15.2 (V-), U15.3 (NC), U17.1, U17.3, U18.3 (GND), U19.3 (GND), U20.5 (GND), U20.8 (GND), U20.9 (GND), U21.2 (GND), U22.1, U22.3, U23.2 (V-), U23.6 (E), U24.2 (V-), U24.6 (E), U25.2, U26.4 (GND), U27.1, U27.3, U28.1, U28.3, U29.1, U29.3, U30.4 (GND), U32.1, U32.3, U35.1, U35.3; also elsewhere on the board
unnamed: C32.1, U16.2 (fast_out)
unnamed: C33.1, L12.1, U21.1 (IN), U21.3 (EN)
unnamed: C34.1, U20.3 (CCAP)
unnamed: C37.1, U20.7 (OUT+)
unnamed: C37.2, R63.1, R64.2
unnamed: C38.1, U20.6 (OUT-)
unnamed: C44.1, C45.1, L14.1, R66.2
unnamed: C46.1, C49.1, L16.2, U23.4 (V+)
unnamed: C47.1, C50.1, L17.2, U24.4 (V+)
unnamed: C48.1, C51.1, L18.1, R66.1, R68.1
unnamed: C52.1, C53.1, L15.1, U26.8 (VCC)
unnamed: C54.1, L19.2, R69.2, U25.3
unnamed: C57.1, C58.1, L20.1, U30.8 (VCC)
unnamed: C62.1, R77.1, TP9.1, U24.3 (+)
unnamed: C63.1, R76.1, U23.3 (+)
unnamed: C64.2, L21.2, R78.1, R79.2
unnamed: C70.2, U25.1
unnamed: C81.1, R70.2, R72.1
unnamed: D3.1 (APD+), U20.2 (IN)
unnamed: D4.1 (K), R60.2
unnamed: D4.2 (A), R57.2, U18.4 (NO)
unnamed: L18.2, L19.1, R68.2, R69.1
unnamed: R14.2, U32.2
unnamed: R53.1, R55.2, U16.3 (cathode)
unnamed: R54.1, R56.1, U20.4 (OFFSET)
unnamed: R55.1, U17.2
unnamed: R58.2, U19.4 (NO)
unnamed: R61.1, U22.2
unnamed: R72.2, U29.2
unnamed: R89.1, U35.2
unnamed: R89.2, U30.3 (Y2)
unnamed: R90.1, U27.2
unnamed: R90.2, U30.5 (A2), U30.6 (B2), U30.7 (Y1)
unnamed: R91.1, U28.2
unnamed: R91.2, U26.7 (Y1)
unnamed: U23.5, U30.1 (A1), U30.2 (B1)
unnamed: U24.5, U26.1 (A1), U26.2 (B1)

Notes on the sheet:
Biasing
Bias-T for RF-amp
optional filtering
APD
SiPM
RF-Amp
Lock-in Amp
Comparator

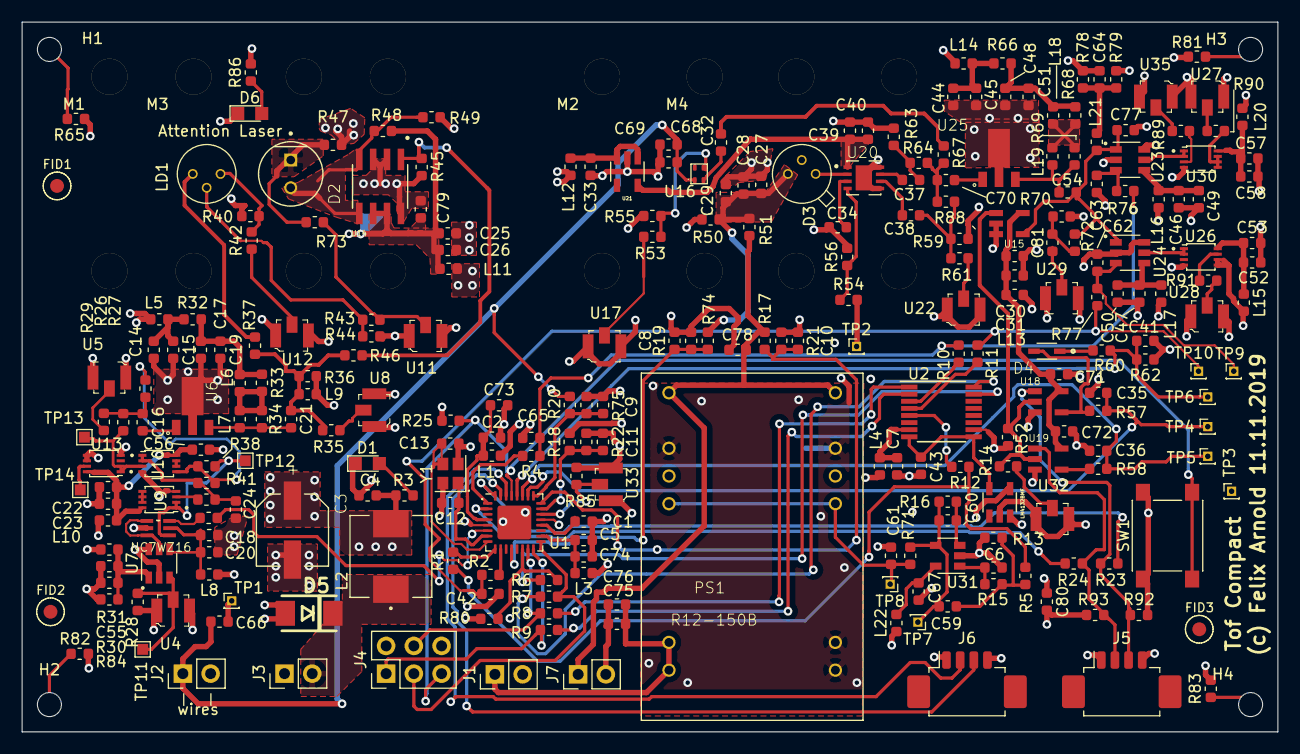
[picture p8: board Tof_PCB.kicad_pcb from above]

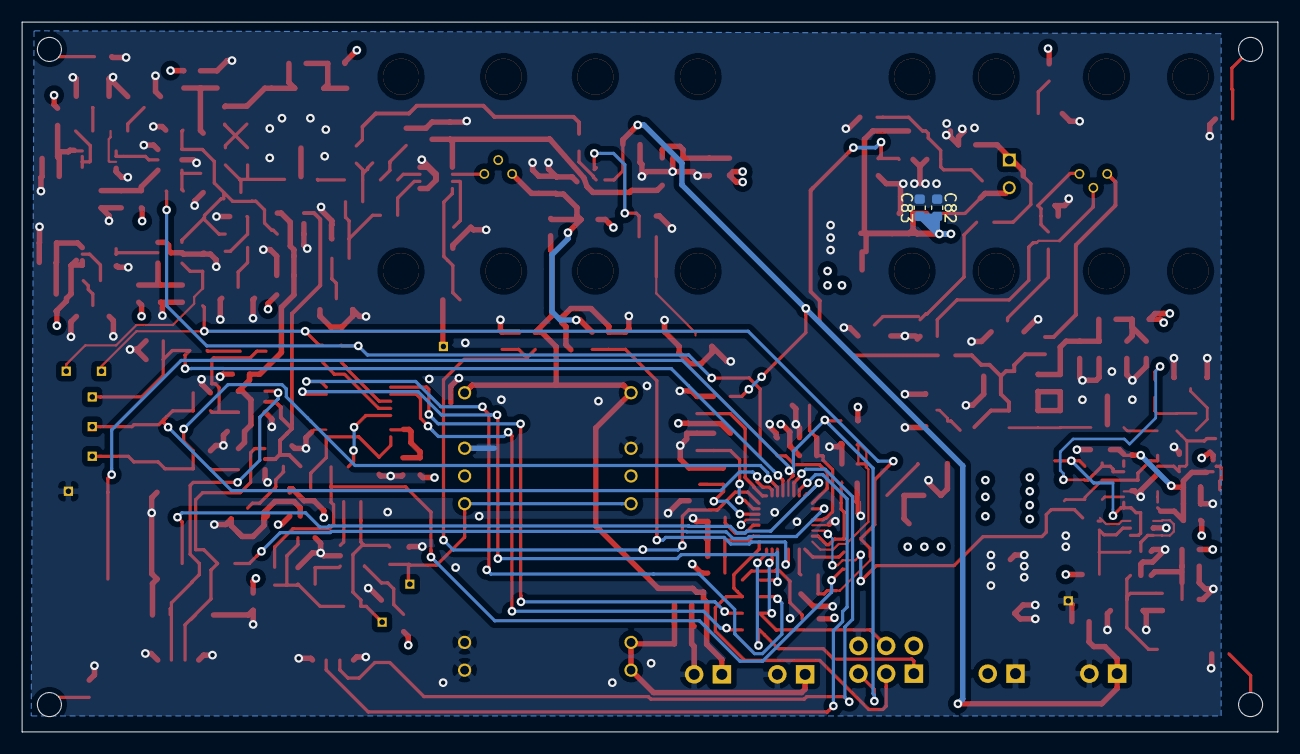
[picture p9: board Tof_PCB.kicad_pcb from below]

Board: 4 copper layers, 115.0 x 65.0 mm, 275 parts (2 on the bottom side), 135 nets.

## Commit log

2019-11-01 Initial commit (schematic + placement)
    [Tof_PCB.kicad_pcb, Tof_PCB.sch, Tof_Rx.sch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]
2019-11-06 Added RLC values
    [Tof_PCB.kicad_pcb, Tof_PCB.sch, Tof_Rx.sch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]
2019-11-07 Added more digikey numbers in BOM
    [Tof_PCB.kicad_pcb, Tof_PCB.sch, Tof_Rx.sch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]
2019-11-07 solved drc errors
    [Tof_PCB.kicad_pcb, Tof_PCB.sch, Tof_Rx.sch]
2019-11-15 Version 1.0. As ordered at PCBWay on 13.11.2019
    [Tof_PCB.kicad_pcb, Tof_Rx.sch, Tof_Tx.sch]
2019-11-23 This is the actual pcb ordered by PCBWay 13.11.2019 The last commit had an error in the schematic files
    Revert "Version 1.0. As ordered at PCBWay on 13.11.2019"
    This reverts commit d90296e8e464a35f67a5ff7ebe731cf47d5f6555.
    [Tof_PCB.kicad_pcb, Tof_Rx.sch, Tof_Tx.sch]
2019-11-25 changed 100k resistor and tlv3501 digikey numbers
    [Tof_PCB.sch, Tof_Rx.sch, Tof_Tx.sch]
2024-08-07 added schematics
    [bom_grouped.xlsx]
